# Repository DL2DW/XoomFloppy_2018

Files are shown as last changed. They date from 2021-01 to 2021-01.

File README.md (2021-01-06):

# XoomFloppy - Elegant XUM1541 version

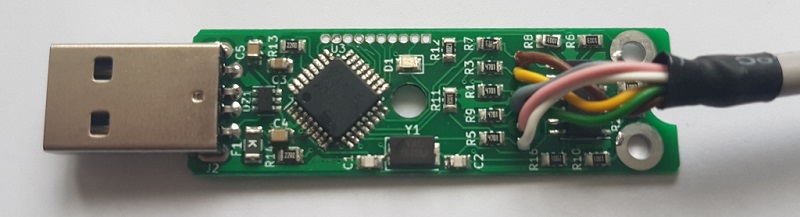
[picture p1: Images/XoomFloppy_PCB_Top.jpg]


## Introduction

The XUM1541 is an adapter that allows Commodore peripherals, such as floppy drives and printers, to be connected to a PC via USB. So you can easily read or write floppy disks from a PC to a 1541. 

The ZoomFloppy is a commercial and very well known version of the XUM1541, which offers some other advantages.

The ZoomFloppy has become a de facto standard, especially concerning the firmware. 

For some applications, for example when I only need the IEC bus, the ZoomFloppy is just too big, so I developed a miniature version of the ZoomFloppy. The result is the XoomFloppy, a 100% compatible clone, running the original firmware of the ZoomFloppy.

# Technical

I basically just shrunk the ZoomFloppy. This, of course, eliminated the IEEE-488 and parallel port.

But the hardware base is otherwise the same. This makes the XoomFloppy the only other device that is 100% compatible. 

The core is the ATmega32u2, on which the original firmware of the ZoomFloppy is flashed. But also the driver module 7406 is present.

In the Docs folder I put a manual in German, which explains the assembly and the subsequent installation of the firmware.

# Case

From the company [Richard Wöhr GmbH](http://www.woehrgmbh.de/) there is a small USB case in which my board fits perfectly. So you can also upgrade the whole thing very elegant. And the electronics are very well protected.

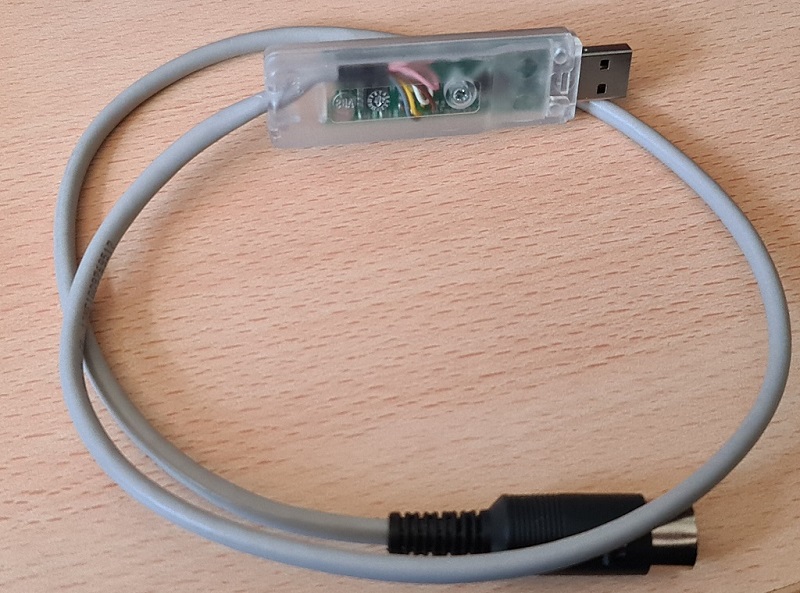
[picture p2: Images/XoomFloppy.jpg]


The order number for the transparent version shown here is: [GH02SG001](https://www.industriegehaeuse.de/fileadmin/pdfs/steckergehaeuse/gh02sg001_verschraubbar_mit_kabelausgang.pdf)

# BOM

The parts list consists of commercially available parts, which should actually be easy to obtain.

| | Description | Part | References | Value | Footprint | Quantity Per PCB |
| ---- | --- | --- | --- | --- | --- | --- |
| 1 | Unpolarized capacitor | C | C4 C5 | 100nF | C_0805_2012Metric | 2 |
| 2 | Unpolarized capacitor | C | C3 | 1µF | C_0805_2012Metric | 1 |
| 3 | Unpolarized capacitor | C | C1 C2 | 22pF | C_0805_2012Metric | 2 |
| 4 | Light emitting diode | LED | D1 | LED Blue | LED_0805_2012Metric | 1 |
| 5 | TVS.3 3.5pF [SOT-23-6] | USBLC6-2SC6 | DZ1 | USBLC6-2SC6 | SOT-23-6 | 1 |
| 6 | Resettable fuse, polymeric positive temperature coefficient | Polyfuse | F1 | Polyfuse 1206L150 | Fuse_1206_3216Metric | 1 |
| 7 | | 7406D | IC1 | 7406D | SOIC-14_3.9x8.7mm_P1.27mm | 1 |
| 8 | USB Type A connector | USB_A | J2 | USB_A | USB_Male_A_UP2-AH-1-TH | 1 |
| 9 | Resistor | R | R2 R4 R6 R8 R10 R11 | 100k | R_0805_2012Metric | 6 |
| 10 | Resistor | R | R16 | 10k | R_0805_2012Metric | 1 |
| 11 | Resistor | R | R12 | 120 | R_0805_2012Metric | 1 |
| 12 | Resistor | R | R13 R14 | 22 | R_0805_2012Metric | 2 |
| 13 | Resistor | R | R1 R3 R5 R7 R9 | 4k7 | R_0805_2012Metric | 5 |
| 14 | 16MHz, 32kB Flash, 1kB SRAM, 1kB EEPROM, TQFP-32 | ATmega32U2-AU | U3 | ATmega32U2-AU | TQFP-32_7x7mm_P0.8mm | 1 |
| 15 | Two pin crystal | Crystal | Y1 | 16MHz | Crystal_SMD_5032-2Pin_5.0x3.2mm | 1 |

# PCB

The PCB can either be ordered directly from [PCBWay](https://www.pcbway.com/project/shareproject/XommFloppy___Elegant_XUM1541_version.html), or you can create it yourself from the Gerber files available here.

PCBWay (https://www.pcbway.com/project/shareproject/XommFloppy___Elegant_XUM1541_version.html)

If you liked my project, I would be very happy about a small coffee donation.



# License

The contents of this repository, with the exception of the Docs and Software directories, are released under the following license:

- the "Creative Commons Attribution-NonCommercial-ShareAlike 4.0 International License" (CC BY-NC-SA 4.0) full text of this license is included in the [LICENSE.CC-NC-BY-SA-4.0](https://github.com/DL2DW/XoomFloppy_2018/blob/main/LICENSE.CC-NC-BY-SA) file and a copy can also be found at https://creativecommons.org/licenses/by-nc-sa/4.0/

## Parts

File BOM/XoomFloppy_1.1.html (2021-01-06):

Source File | /Volumes/Daten/Elektronik/KiCad Neu/final/XoomFloppy/XoomFloppy.sch
BoM Date | Freitag, 24. Mai 2019 um 14:16:58
Schematic Version | 1.1
Schematic Date | 2019-05-24
KiCad Version | Eeschema (5.1.2-1)-1
Component Groups | 21
Component Count (per PCB) | 33
Fitted Components (per PCB) | 27
Number of PCBs | 1
Total Component Count (for 1 PCBs) | 27
 | Description | Part | References | Value | Footprint | Quantity Per PCB | Datasheet | BOM | Config
1 | Unpolarized capacitor | C | C4 C5 | 100nF | C_0805_2012Metric | 2 | ~
2 | Unpolarized capacitor | C | C3 | 1µF | C_0805_2012Metric | 1 | ~
3 | Unpolarized capacitor | C | C1 C2 | 22pF | C_0805_2012Metric | 2 | ~
4 | Light emitting diode | LED | D1 | LED Blue | LED_0805_2012Metric | 1 | ~
5 | TVS.3 3.5pF [SOT-23-6] | USBLC6-2SC6 | DZ1 | USBLC6-2SC6 | SOT-23-6 | 1 | http://www.st.com/web/en/resource/technical/document/datasheet/CD00050750.pdf | TVS ST USBLC6-2SC6
6 | Resettable fuse, polymeric positive temperature coefficient | Polyfuse | F1 | Polyfuse 1206L150 | Fuse_1206_3216Metric | 1 | ~
7 |  | 7406D | IC1 | 7406D | SOIC-14_3.9x8.7mm_P1.27mm | 1
8 | USB Type A connector | USB_A | J2 | USB_A | USB_Male_A_UP2-AH-1-TH | 1 | ~
9 | Resistor | R | R2 R4 R6 R8 R10 R11 | 100k | R_0805_2012Metric | 6 | ~
10 | Resistor | R | R16 | 10k | R_0805_2012Metric | 1 | ~
11 | Resistor | R | R12 | 120 | R_0805_2012Metric | 1 | ~
12 | Resistor | R | R13 R14 | 22 | R_0805_2012Metric | 2 | ~
13 | Resistor | R | R1 R3 R5 R7 R9 | 4k7 | R_0805_2012Metric | 5 | ~
14 | 16MHz, 32kB Flash, 1kB SRAM, 1kB EEPROM, TQFP-32 | ATmega32U2-AU | U3 | ATmega32U2-AU | TQFP-32_7x7mm_P0.8mm | 1 | http://ww1.microchip.com/downloads/en/DeviceDoc/doc7799.pdf
15 | Two pin crystal | Crystal | Y1 | 16MHz | Crystal_SMD_5032-2Pin_5.0x3.2mm | 1 | ~

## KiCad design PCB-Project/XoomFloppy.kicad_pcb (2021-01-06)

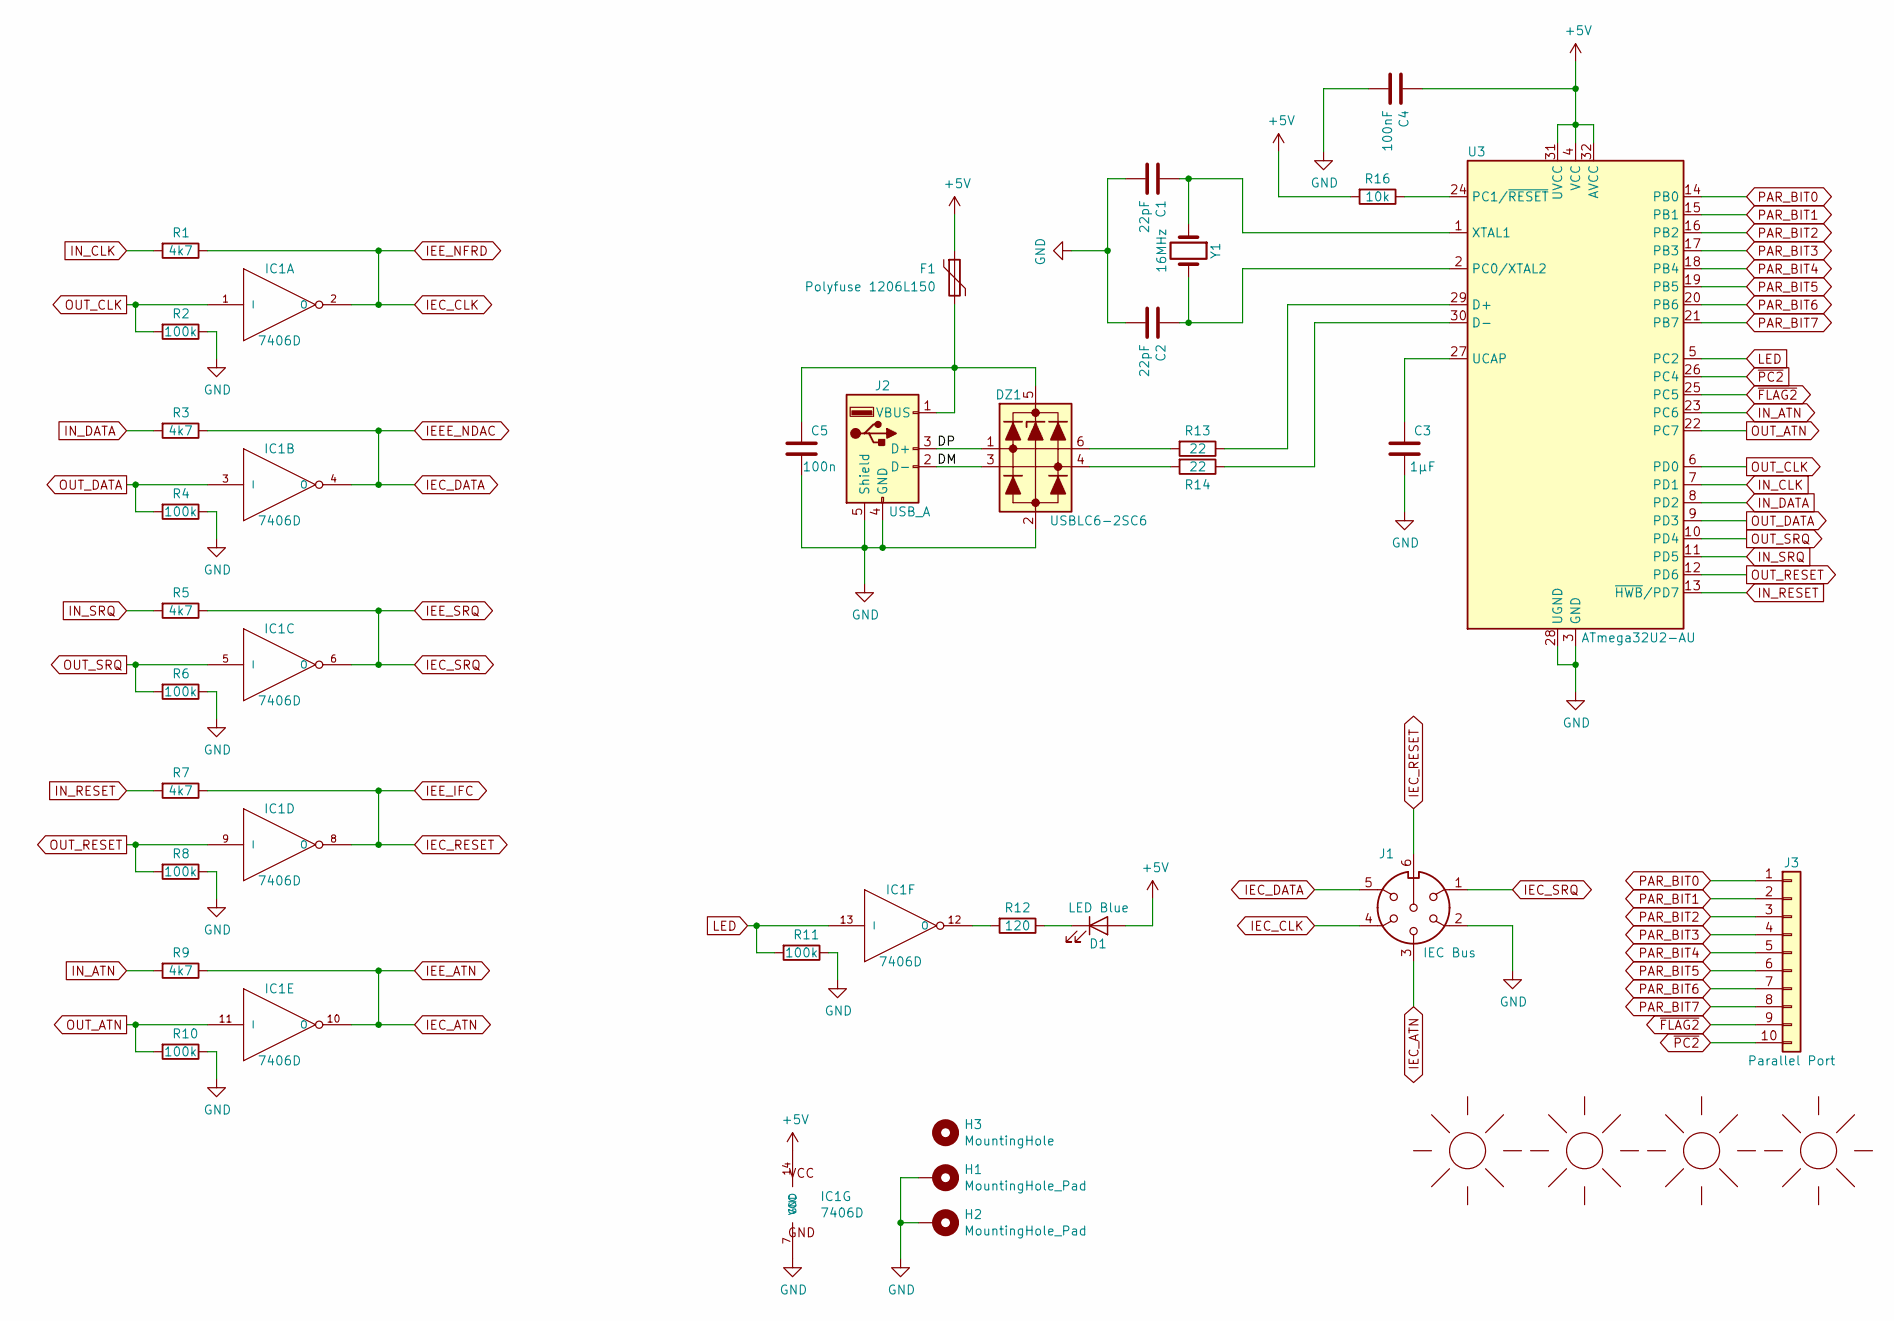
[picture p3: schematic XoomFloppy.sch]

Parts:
C1, C2: 22pF; C_0805_2012Metric
C3: 1µF; C_0805_2012Metric
C4: 100nF; C_0805_2012Metric
C5: 100n; C_0805_2012Metric
D1: LED Blue; LED_0805_2012Metric
DZ1: USBLC6-2SC6; SOT-23-6
F1: Polyfuse 1206L150; Fuse_1206_3216Metric
H1, H2: MountingHole_Pad; MountingHole_2.7mm_M2.5_Pad
H3: MountingHole; MountingHole_4mm
IC1: 7406D; SOIC-14_3.9x8.7mm_P1.27mm
J1: IEC Bus; PinHeader_1x06_P2.00mm_Vertical
J2: USB_A; USB_Male_A_UP2-AH-1-TH
J3: Parallel Port; PinHeader_1x10_P1.27mm_Vertical
M1: SUNLOGO; KiCad-Logo2_6mm_SilkScreen
M2: SUNLOGO; Logo_silk_CC-BY-NC-SA_5x2mm
M3: SUNLOGO; Logo_silk_OSHW_6x6mm
M4: SUNLOGO; DL2DW_Logo_Silk_10x5mm
R1, R3, R5, R7, R9: 4k7; R_0805_2012Metric
R2, R4, R6, R8, R10, R11: 100k; R_0805_2012Metric
R12: 120; R_0805_2012Metric
R13, R14: 22; R_0805_2012Metric
R16: 10k; R_0805_2012Metric
U3: ATmega32U2-AU; TQFP-32_7x7mm_P0.8mm
Y1: 16MHz; Crystal_SMD_5032-2Pin_5.0x3.2mm

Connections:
+5V: C4.2, D1.2 (A), F1.1, IC1.14 (VCC), R16.2, U3.4 (VCC), U3.31 (UVCC), U3.32 (AVCC)
/DM: DZ1.3, J2.2 (D-)
/DP: DZ1.1, J2.3 (D+)
GND: C1.2, C2.2, C3.1, C4.1, C5.1, DZ1.2, H1.1, H2.1, IC1.7 (GND), J1.2, J2.4 (GND), J2.5 (Shield), R2.1, R4.1, R6.1, R8.1, R10.1, R11.1, U3.3 (GND), U3.28 (UGND)
IEC_ATN: IC1.10 (O), J1.3, R9.1
IEC_CLK: IC1.2 (O), J1.4, R1.1
IEC_DATA: IC1.4 (O), J1.5, R3.1
IEC_RESET: IC1.8 (O), J1.6, R7.1
IEC_SRQ: IC1.6 (O), J1.1, R5.1
IN_ATN: R9.2, U3.23 (PC6)
IN_CLK: R1.2, U3.7 (PD1)
IN_DATA: R3.2, U3.8 (PD2)
IN_RESET: R7.2, U3.13 (~HWB~/PD7)
IN_SRQ: R5.2, U3.11 (PD5)
LED: IC1.13 (I), R11.2, U3.5 (PC2)
unnamed: C1.1, U3.1 (XTAL1), Y1.1
unnamed: C2.1, U3.2 (PC0/XTAL2), Y1.2
unnamed: C3.2, U3.27 (UCAP)
unnamed: C5.2, DZ1.5, F1.2, J2.1 (VBUS)
unnamed: D1.1 (K), R12.1
unnamed: DZ1.4, R14.2
unnamed: DZ1.6, R13.2
unnamed: IC1.12 (O), R12.2
unnamed: R13.1, U3.29 (D+)
unnamed: R14.1, U3.30 (D-)
unnamed: R16.1, U3.24 (PC1/~RESET)
OUT_ATN: IC1.11 (I), R10.2, U3.22 (PC7)
OUT_CLK: IC1.1 (I), R2.2, U3.6 (PD0)
OUT_DATA: IC1.3 (I), R4.2, U3.9 (PD3)
OUT_RESET: IC1.9 (I), R8.2, U3.12 (PD6)
OUT_SRQ: IC1.5 (I), R6.2, U3.10 (PD4)
PAR_BIT0: J3.1, U3.14 (PB0)
PAR_BIT1: J3.2, U3.15 (PB1)
PAR_BIT2: J3.3, U3.16 (PB2)
PAR_BIT3: J3.4, U3.17 (PB3)
PAR_BIT4: J3.5, U3.18 (PB4)
PAR_BIT5: J3.6, U3.19 (PB5)
PAR_BIT6: J3.7, U3.20 (PB6)
PAR_BIT7: J3.8, U3.21 (PB7)
~FLAG2: J3.9, U3.25 (PC5)
~PC2: J3.10, U3.26 (PC4)

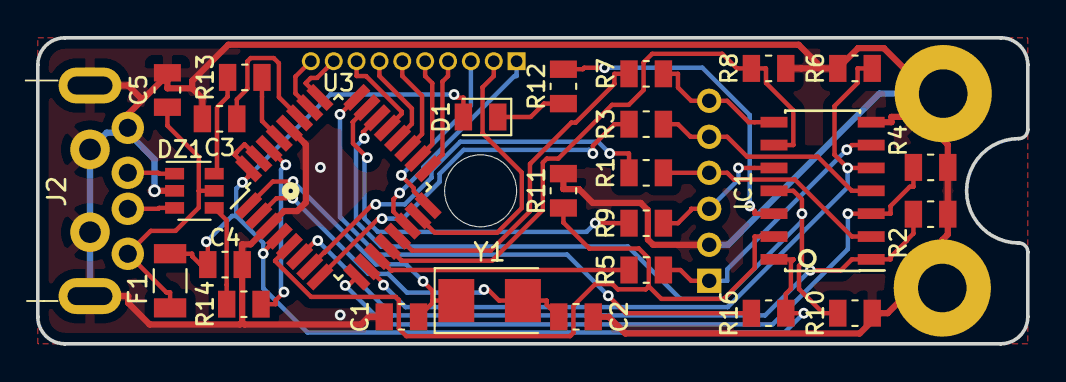
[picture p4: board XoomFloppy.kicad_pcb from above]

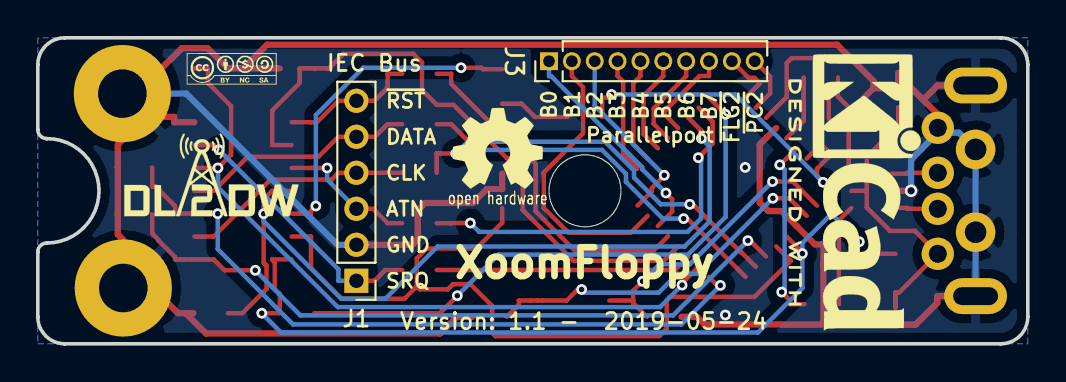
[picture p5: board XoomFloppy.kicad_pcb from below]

Board: 2 copper layers, 55.0 x 17.0 mm, 36 parts (6 on the bottom side), 41 nets.
